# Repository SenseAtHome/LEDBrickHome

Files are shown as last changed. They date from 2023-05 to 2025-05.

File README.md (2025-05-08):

# LEDBrickHome

Wi-Fi controller compatible with various Lego Lighting kits, designed to enable integration of lighting into Home Assistant via ESPHome.  Supports single colour and RGB dimmable lights, lighting effects and use in scenes.

Video of lighting in action

## Versions

> [!WARNING]  
> Versions up to and included v1.1 have a hardware design issue that prevents the use of USB-C to USB-C cables.  They will work correctly with USB-A to USB-C cables.

Different versions of LEDBrickHome may exist in the future with different numbers of output connectors (e.g. to reduce cost or size).

To maximise available number of channels, RGB (4-pin) outputs are shared with single colour (2-pin) outputs.  In other words, a 16 PWM controller can support a total of 16 different outputs of a single colour, but for each RGB output used, three single colour outputs are lost.

| Version | Total PWM Outputs | 2-pin outputs | 4-pin outputs | Dimensions |
| --- | --- | --- | --- | --- |
| 16ch-v1.0 | 16 | 16 | 5 | 96 x 45 mm |
| 16ch-v1.1 | 16 | 16 | 5 | 68 x 45 mm |

### 16ch-v1

16ch-v1 is based on an ESP32-WROOM (exact memory size does not matter), uses a CP2102N ([drivers](https://www.silabs.com/developers/usb-to-uart-bridge-vcp-drivers?tab=downloads)) for it's USB->UART bridge, and is powered by a USB-C connector.  Outputs are grouped in blocks and identified on the silkscreen which 2-pin outputs are shared with 4-pin outputs.

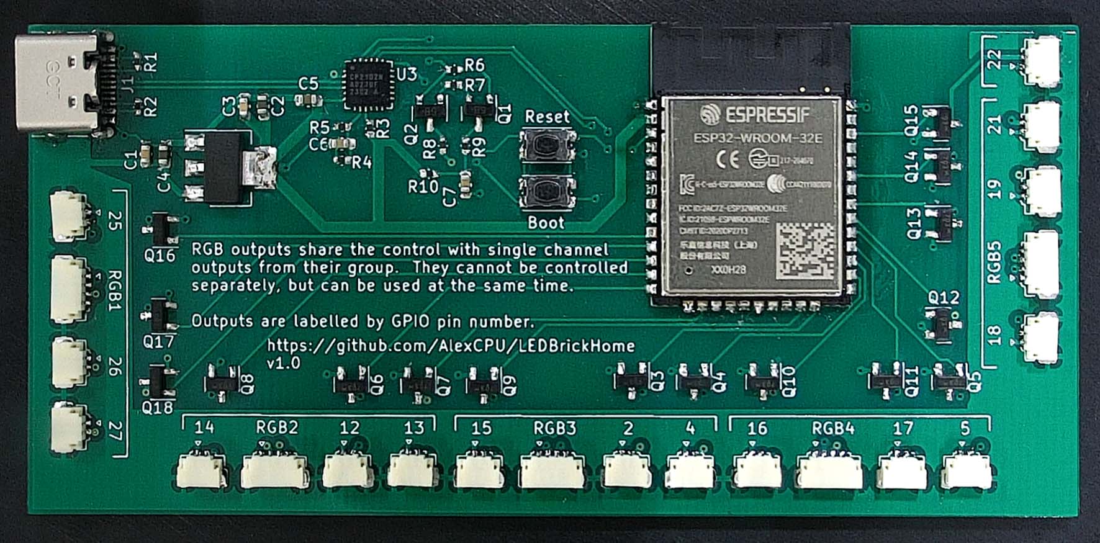
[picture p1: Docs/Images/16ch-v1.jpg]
PCB showing ESP32 and output connectors


### 16ch-v1.1

16ch-v1.1 is a smaller version of the previous 16ch design, using a CH340C ([drivers](http://www.wch-ic.com/downloads/CH341SER_ZIP.html)) for it's USB->UART bridge, but is otherwise functionally identical.

## Effects
Various effects are available in ESPHome, which are explained in the [documentation](https://esphome.io/components/light/index.html#light-effects), some of these are included in the code examples already.  For flickering torch effects, the default flicker intensity (of 1.5%) will want to be increased.  The demo video above has flicker set at 10%.

## Compatibility

LEDBrickHome is compatible with lighting kits that use a JST SUR connector with 5V on pin 1, and switched 0V on pin 2 (plus pins 3 & 4 for RGB connectors).

The below table shows the results of our testing.  You should verify connector type and pinout yourself for your own project.

| Light System | Compatible? | Notes |
| --- | --- | --- |
| Light My Bricks V1 | :white_check_mark: | | 
| Light My Bricks V2 | :x: | Swapped to a flat ribbon style connector |
| Briksmax V1 | :white_check_mark: | |
| Briksmax V2 | :x: | Similar but not compatible with JST SUR |
| Kyglaring | :white_check_mark: | |

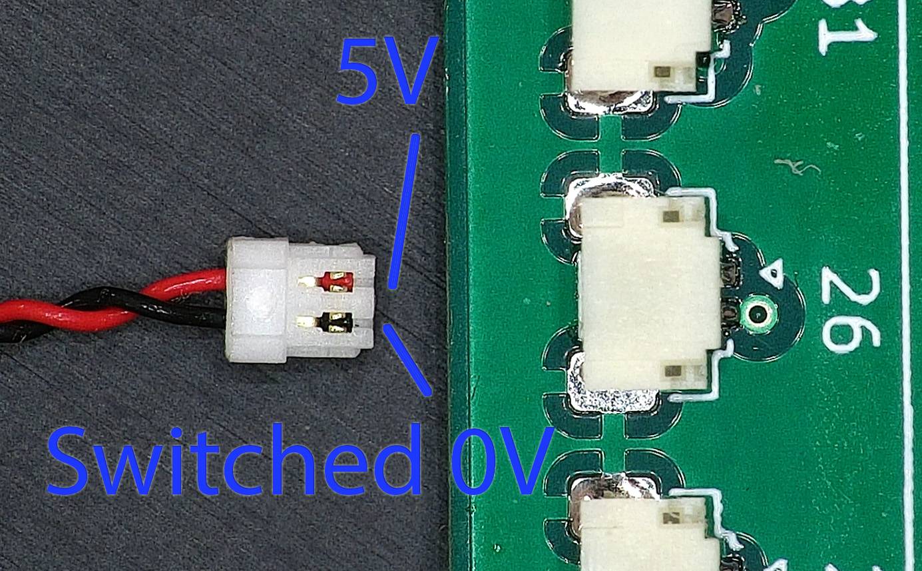
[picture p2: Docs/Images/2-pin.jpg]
2 pin JST SUR connector


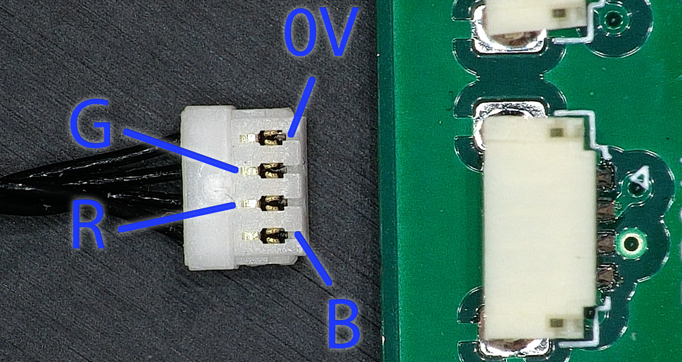
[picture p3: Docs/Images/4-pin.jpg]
4 pin JST SUR connector

Note, order of Red, Green and Blue channels is not important and can be changed in your configuration file.

## PCB Design

The PCB design is created in KiCAD V7, and is a simple 2-layer PCB.

## Tips
* Do not add the web server to the code, this seems to cause the ESP32 to reboot regularly.
* Boot and Reset buttons are included, but shouldn't be required for programming
* Original ESP32's are used rather than newer parts (e.g. S3, C3, etc.) as the original parts support 16 PWM outputs, whereas the newer parts only support 8 PWM outputs.
* RGB outputs may need their output channels swapping if the colour mapping is wrong. i.e. if you ask for Red but get Green, change the appropriate lines in your configuration file.

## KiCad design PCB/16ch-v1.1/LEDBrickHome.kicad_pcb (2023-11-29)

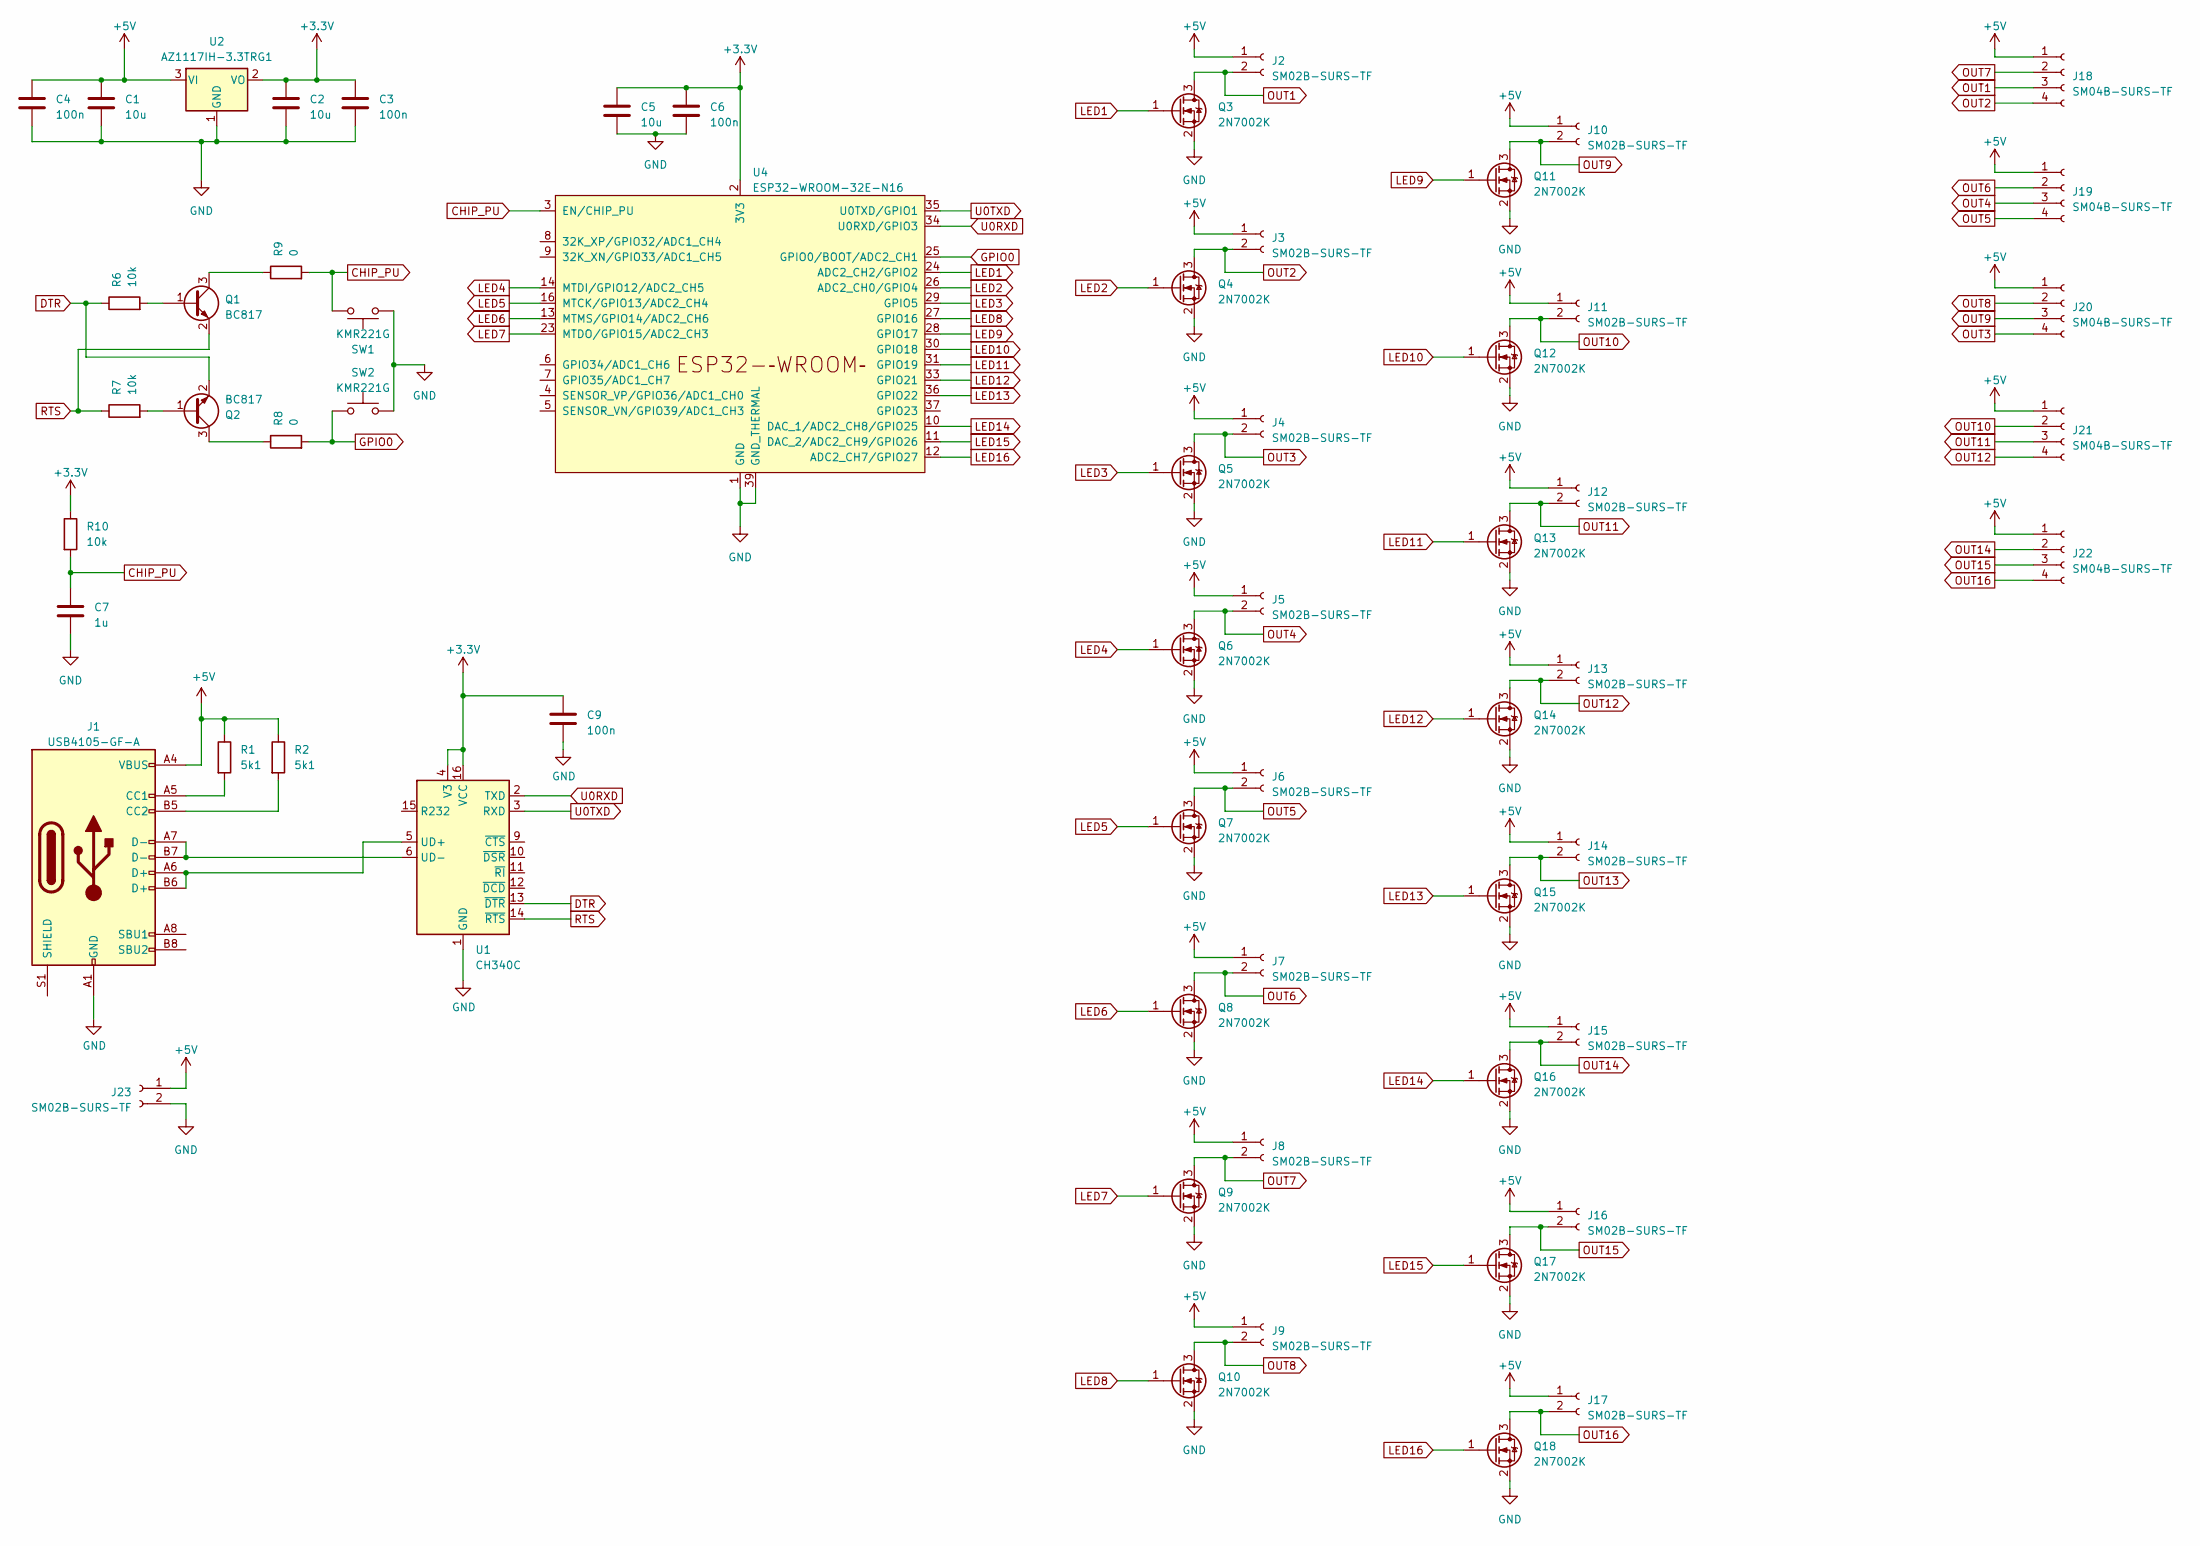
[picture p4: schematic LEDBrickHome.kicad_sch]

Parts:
C1, C2, C5: 10u; C_0603_1608Metric
C3, C4, C6, C9: 100n; C_0603_1608Metric
C7: 1u; C_0603_1608Metric
J1: USB4105-GF-A; USB_C_Receptacle_GCT_USB4105-xx-A_16P_TopMnt_Horizontal
J2, J3, J4, J5, J6, J7, J8, J9, J10, J11, J12, J13, J14, J15, J16, J17, J23: SM02B-SURS-TF; JST_SUR_SM02B-SURS-TF_1x02-1MP_P0.80mm_Horizontal
J18, J19, J20, J21, J22: SM04B-SURS-TF; JST_SUR_SM04B-SURS-TF_1x04-1MP_P0.80mm_Horizontal
Q1, Q2: BC817; SOT-23
Q3, Q4, Q5, Q6, Q7, Q8, Q9, Q10, Q11, Q12, Q13, Q14, Q15, Q16, Q17, Q18: 2N7002K; SOT-23
R1, R2: 5k1; R_0402_1005Metric
R6, R7, R10: 10k; R_0402_1005Metric
R8, R9: 0; R_0402_1005Metric
SW1, SW2: KMR221G; SW_Push_1P1T_NO_CK_KMR2
U1: CH340C; SOIC-16_3.9x9.9mm_P1.27mm
U2: AZ1117IH-3.3TRG1; SOT-223-3_TabPin2
U4: ESP32-WROOM-32E-N16; ESP32-WROOM-32E

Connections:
+3.3V: C2.2, C3.2, C5.2, C6.2, C9.2, R10.1, U1.4 (V3), U1.16 (VCC), U2.2 (VO), U4.2 (3V3)
+5V: C1.2, C4.2, J1.A4 (VBUS), J1.A9 (VBUS), J1.B4 (VBUS), J1.B9 (VBUS), J2.1, J2.MP, J3.1, J3.MP, J4.1, J4.MP, J5.1, J5.MP, J6.1, J6.MP, J7.1, J7.MP, J8.1, J8.MP, J9.1, J9.MP, J10.1, J10.MP, J11.1, J11.MP, J12.1, J12.MP, J13.1, J13.MP, J14.1, J14.MP, J15.1, J15.MP, J16.1, J16.MP, J17.1, J17.MP, J18.1, J18.MP, J19.1, J19.MP, J20.1, J20.MP, J21.1, J21.MP, J22.1, J22.MP, J23.1, J23.MP, R1.1, R2.1, U2.3 (VI)
CHIP_PU: C7.2, R9.2, R10.2, SW1.1, U4.3 (EN/CHIP_PU)
DTR: Q2.2 (E), R6.1, U1.13 (~DTR)
GND: C1.1, C2.1, C3.1, C4.1, C5.1, C6.1, C7.1, C9.1, J1.A1 (GND), J1.A12 (GND), J1.B1 (GND), J1.B12 (GND), J23.2, Q3.2 (S), Q4.2 (S), Q5.2 (S), Q6.2 (S), Q7.2 (S), Q8.2 (S), Q9.2 (S), Q10.2 (S), Q11.2 (S), Q12.2 (S), Q13.2 (S), Q14.2 (S), Q15.2 (S), Q16.2 (S), Q17.2 (S), Q18.2 (S), SW1.2, SW2.2, U1.1 (GND), U2.1 (GND), U4.1 (GND), U4.15 (GND), U4.38 (GND), U4.39 (GND_THERMAL)
GPIO0: R8.2, SW2.1, U4.25 (GPIO0/BOOT/ADC2_CH1)
LED1: Q3.1 (G), U4.24 (ADC2_CH2/GPIO2)
LED2: Q4.1 (G), U4.26 (ADC2_CH0/GPIO4)
LED3: Q5.1 (G), U4.29 (GPIO5)
LED4: Q6.1 (G), U4.14 (MTDI/GPIO12/ADC2_CH5)
LED5: Q7.1 (G), U4.16 (MTCK/GPIO13/ADC2_CH4)
LED6: Q8.1 (G), U4.13 (MTMS/GPIO14/ADC2_CH6)
LED7: Q9.1 (G), U4.23 (MTDO/GPIO15/ADC2_CH3)
LED8: Q10.1 (G), U4.27 (GPIO16)
LED9: Q11.1 (G), U4.28 (GPIO17)
LED10: Q12.1 (G), U4.30 (GPIO18)
LED11: Q13.1 (G), U4.31 (GPIO19)
LED12: Q14.1 (G), U4.33 (GPIO21)
LED13: Q15.1 (G), U4.36 (GPIO22)
LED14: Q16.1 (G), U4.10 (DAC_1/ADC2_CH8/GPIO25)
LED15: Q17.1 (G), U4.11 (DAC_2/ADC2_CH9/GPIO26)
LED16: Q18.1 (G), U4.12 (ADC2_CH7/GPIO27)
unnamed: J1.A5 (CC1), R1.2
unnamed: J1.B5 (CC2), R2.2
unnamed: Q1.1 (B), R6.2
unnamed: Q1.3 (C), R9.1
unnamed: Q2.1 (B), R7.2
unnamed: Q2.3 (C), R8.1
unnamed: J1.A6 (D+), J1.B6 (D+), U1.5 (UD+)
unnamed: J1.A7 (D-), J1.B7 (D-), U1.6 (UD-)
OUT1: J2.2, J18.3, Q3.3 (D)
OUT2: J3.2, J18.4, Q4.3 (D)
OUT3: J4.2, J20.4, Q5.3 (D)
OUT4: J5.2, J19.3, Q6.3 (D)
OUT5: J6.2, J19.4, Q7.3 (D)
OUT6: J7.2, J19.2, Q8.3 (D)
OUT7: J8.2, J18.2, Q9.3 (D)
OUT8: J9.2, J20.2, Q10.3 (D)
OUT9: J10.2, J20.3, Q11.3 (D)
OUT10: J11.2, J21.2, Q12.3 (D)
OUT11: J12.2, J21.3, Q13.3 (D)
OUT12: J13.2, J21.4, Q14.3 (D)
OUT13: J14.2, Q15.3 (D)
OUT14: J15.2, J22.2, Q16.3 (D)
OUT15: J16.2, J22.3, Q17.3 (D)
OUT16: J17.2, J22.4, Q18.3 (D)
RTS: Q1.2 (E), R7.1, U1.14 (~RTS)
U0RXD: U1.2 (TXD), U4.34 (U0RXD/GPIO3)
U0TXD: U1.3 (RXD), U4.35 (U0TXD/GPIO1)

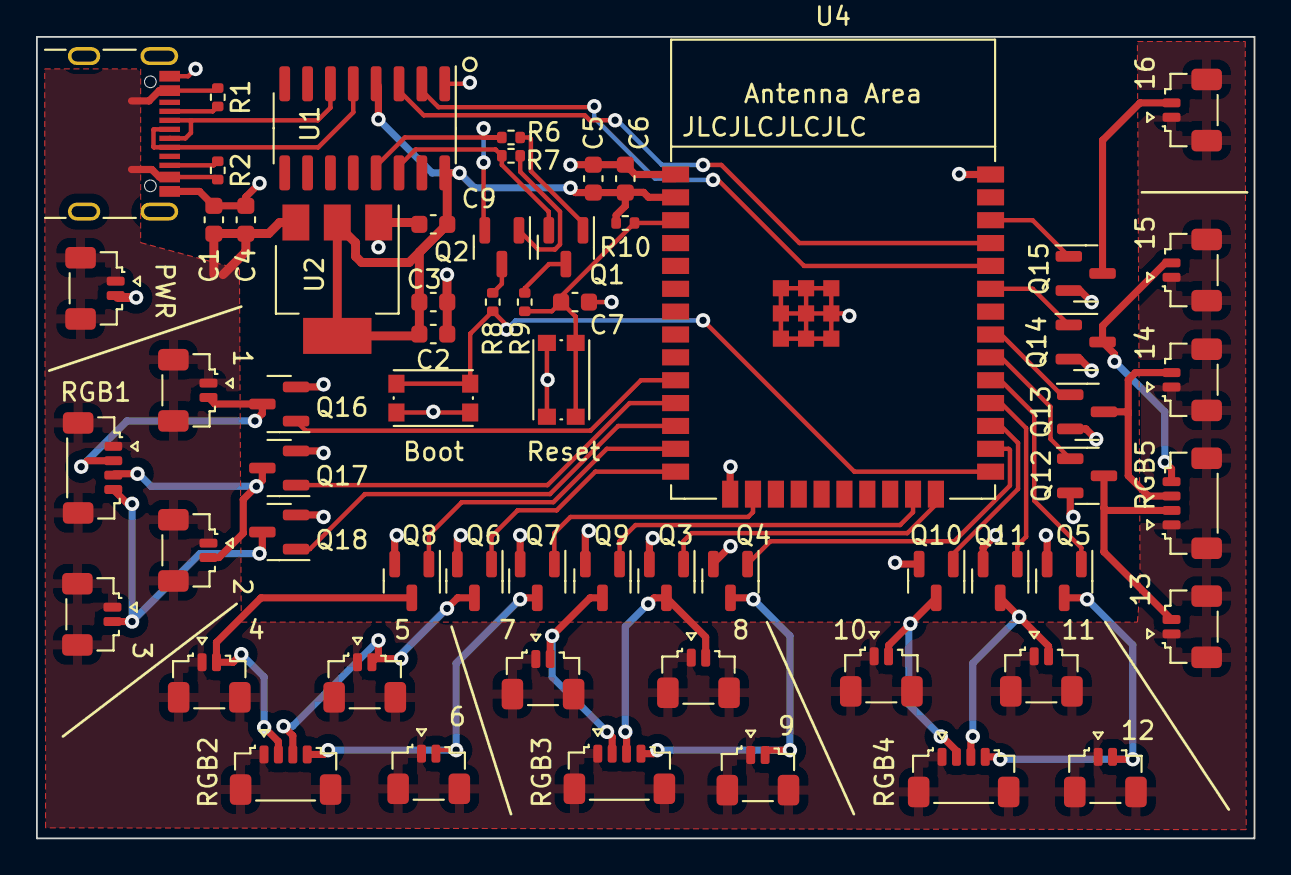
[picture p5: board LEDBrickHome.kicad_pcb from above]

Board: 2 copper layers, 67.6 x 44.5 mm, 61 parts (0 on the bottom side), 49 nets.

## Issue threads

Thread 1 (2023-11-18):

hello nice project!

platini76, 2023-11-18:
please can I know where can I find the board?
thanks!

AlexCPU, 2023-11-19:
There should be everything you need in this repo to build your own, or you can order them from here: https://xelaser.co.uk/product/ledbrickhome-16-channel-version/

Closed 2023-11-19.

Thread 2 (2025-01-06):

Question: Any plans on updates

kl4n4, 2025-01-06:
Hi,

First of all: thank you sharing this awesome project so openly! I was looking for exactly this (some option to control my LEGO lights with HomeAssistant). But since I unfortunately lack the electronic skills to design and build my own ESP32-based PCB I immediately ordered one of yours from xelaser. Unluckily I did not realize LightMyBricks/Briksmax have changed their connectors in the meantime and are not longer using these JST SUR connector types :(

Do you have any plans on updating your PCB with these "Briksmax 2.0" connectors (I have no idea what type of connector this is exactly) but the unfortunately even stopped selling the old connector cables :/

Thanks and greetings from Austria :)

AlexCPU, 2025-01-08:
Oh that's really annoying!  If I can identify the connector then it's possibly, but some quick googling hasn't managed to find out any details about it.  The new LightMyBricks flat ribbon cable might be more of a problem.

As for your existing kit, if you search AliExpress for "lego light cables", you'll get plenty of cheap options for the old connectors, so you could cut off the new ones, cut the AliExpress cables in half, and solder them together, to convert your kit back to the old connectors to work with the board you've got.

Nensec, 2025-01-09:
I've been working on adapting your idea but using generic esp32 devkit boards instead ontop of an adapter board for the connectors and power supply. So if you find out what connectors they use do share that information. I did ask lightmybricks myself already and I got a canned response back that they are proprietary, so one has to get creative on that one.

I have an LMB2.0 set at home here so I will be experimenting a bit on what makes for a secure connection. An obvious work around is using LMB2.0 converter bricks between the JST connectors and their proprietary ones, but that will get costly very quickly 😋

kl4n4, 2025-01-11:
Thanks for these inputs! I will be looking for alternative sources of the old cables and solder them to the new cables ;)

Closed 2025-01-11.

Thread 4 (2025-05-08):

Cannot get board connected with USB

bramstroker, 2025-05-08:
Hi @AlexCPU, thanks for your project — it was exactly what I needed for my MOC build.

I ordered the assembled board from xelaser and received it last week. I finally got around to installing it today, but I'm running into issues connecting the device via USB to flash the firmware.

I first tried on my MacBook Pro, and installed the CH340 driver. However, no new USB devices show up when I check with ls /dev/cu.*, and ESPHome Web also doesn't detect the device. I tried three different cables and all USB ports, and also held the BOOT button while connecting, but still no luck.

Next, I tried a Windows 10 PC, but I don’t hear any USB connection sound when plugging in the board. Even without drivers, I’d expect at least a connection tone.

At this point, I’m suspecting the board might be faulty, but I’m not entirely sure. Any advice on what else I could try?

AlexCPU, 2025-05-08:
Hi @bramstroker,

I did have some issues with USB cables on this latest batch that sound similar to what you are describing, I just found another cable which worked and assumed I had a dodgy cable.  However...

Having now investigated further, it looks like you've found a bug in the hardware design that you're probably more disposed to by only having USB-C ports on the MacBook Pro.

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

R1 and R2 should be pull-down resistors rather than pull-up resistors.  In their current configuration, they are set up to tell the USB-C interface that they are the "host" device, which is why your computer can't see anything, as both ends of the link are claiming to be the host.

I've confirmed this with some USB-C cables, laptops and charger/power-supplies.

If you use a USB-A to USB-C cable, it should power up fine.  And also work with an A-C adapter on the end of that cable (the A end has to be in the laptop not the PCB, as it defines the host end of the cable itself).

One final point, you shouldn't need to program it, they were all programmed and tested before shipping.  Once powered up with an A-C cable, it should put up a Wi-Fi access point for you to connect to and give your network details to.

bramstroker, 2025-05-09:
Thanks for your answer and clarification.

I completely missed the firmware was pre-installed. Just connected the board using a USB charger with A-C cable, and was able to connect to the provided ap. Set up my own WiFi and up and running.
Now I can take control in HA and upload modified firmware using OTA.

Thanks a lot!

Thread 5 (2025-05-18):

Request for PCB Modification Assistance

bramstroker, 2025-05-18:
First of all, thank you for sharing your fantastic PCB project. I’ve been using it as part of a large LEGO MOC I’ve been working on for nearly two years—a detailed church tower made of over 30,000 pieces. Your board has been instrumental in lighting up all the floors with RGB and white lights, and everything works superbly. I really appreciate your work and generosity in making this available.

The model will soon be displayed inside the actual church and later in a local museum. Since not all of these locations have WiFi, I’d like to add some physical push buttons to control the lights offline.

I managed to modify the ESPHome firmware and solder two wires directly to the ESP chip, but it feels quite fragile and not suitable for long-term use. Ideally, I’d love to have a modified version of the PCB that exposes a few additional GPIO pins through JST SUR connectors for button input.

For my needs, just 3 GPIOs and ground would be sufficient—so either one 4-pin connector (GND + 3 GPIO) or three separate plugs would work.
The GPIO pins need to support pullups, not every pin does.

Would you be open to helping with this modification? I’d be happy to pay for your time and effort. Please let me know if this is something you’d consider.

Thanks again for the amazing project

P.S. I couldn't find you contact information. If you'd like to discuss this further as Github issue tracker might not be the right place you can contact me on bgerritsen_at_gmail_dot_com

AlexCPU, 2025-06-04:
I'm very torn on the correct solution for this, mostly around the choice of connector.  I can see the options as:

**2-pin JST SUR**
- Doesn't add another line to the BOM.
- Could be used for extra LEDs (without hardware PWM), although lower voltage and drive current might be an issue.
- Board needs to be larger.

**4-pin JST SUR**
- Doesn't add another line to the BOM
- Could be used for extra RGB LEDs (without hardware PWM), although lower voltage and drive current might be an issue.
- Effectively custom to this request.
- Board needs to be larger.

**Pin Header**
- Could be left to the end user to add, therefore not adding a line to the BOM, keeping just one "active" version of the project.
- User needs to be able to solder to use.
- Board needs to be larger.

**Test points** (holes to solder your own wires to)
- User needs to be able to solder to use.
- Probably could be fitted on the existing board

So I think my preference would be test points, and they could be rolled up into the 1.2 update that fixes #4.

Finally (and I haven't checked this) you've said that GPIO34-39 don't have inbuilt pull-ups, in that case, there's only two pins left (GPIO32-33), so I'm curious which pins you are using.  In theory the UART and Boot pins can be reused, and if I was in control of the hardware, I would reuse them, but I don't think they're a great choice for public facing GPIOs as users could connect things that break the boot sequence, or programming functionality.

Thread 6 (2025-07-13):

Briksmaks V1.1

Schattenruf, 2025-07-13:
Hi,

I bought your Board and the briksmaks v1.1 Kit for barad dur. But this connector does not seem to be compatible as far as I can see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

The Board seems to have smaller connectors than the briksmaks ones. I think the recommandation about briksmaks need to be changed :(
Sadly that is what I went after...

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

AlexCPU, 2025-07-13:
Duplicate of #2

The readme/description was updated back in January to reflect the change of connector from various vendors including Briksmax, and has always had a note saying you should verify connectors and pinouts for your project. (https://github.com/SenseAtHome/LEDBrickHome/blame/1099f178986a1b3c88ba9959eac5e6fbd6b0459e/README.md#L38)

Your pictures show the new version two connector.  I expect the V1.1.0 on your box refers to the version of the Barad Dur kit.

Briksmax do have an adapter available that you can use to convert between the two connector types: https://www.briksmax.com/products/connector-converter-three-pack-resolving-compatibility-issues-between-new-and-old-connectors

Closed 2025-07-13.

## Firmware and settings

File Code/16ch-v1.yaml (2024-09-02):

substitutions:
  name: "ledbrickhome-16ch"
  friendly_name: "LEDBrickHome"
  project_name: "SenseAtHome.ledbrickhome-16ch"
  project_version: "1.0"
  hidden_ssid: "false"

esphome:
  name: "${name}"
  name_add_mac_suffix: true
  project:
    name: "${project_name}"
    version: "${project_version}"

esp32:
  board: esp32dev
  framework:
    type: arduino
    version: recommended

logger:

api:

ota:
  - platform: esphome

wifi:
  fast_connect: ${hidden_ssid}
  ap: {}

captive_portal:

improv_serial:

esp32_improv:
  authorizer: none
  
dashboard_import:
  package_import_url: github://AlexCPU/LEDBrickHome/Code/16ch-v1.yaml@main
  import_full_config: true

binary_sensor:
  - platform: status
    name: "${friendly_name} Status"

sensor:
  - platform: uptime
    name: "${friendly_name} Uptime"
    disabled_by_default: true

button:
  - platform: restart
    id: restart_button
    name: "${friendly_name} Restart"
  - platform: factory_reset
    name: Restart with Factory Default Settings

time:
  - platform: sntp

switch:
  - platform: factory_reset
    name: Factory Reset

text_sensor:
  - platform: wifi_info
    ip_address:
      name: "${friendly_name} IP Address"
      disabled_by_default: true

light:
# Details for each of the outputs.
# see https://esphome.io/components/light/index.html#light-effects for configuration
# of light effects

# Group 1:
# to use RGB light, uncomment it's section and comment the monochromatic lights
  - platform: monochromatic
    name: "Channel 1"
    output: output_ch1
    effects:
      - pulse:
      - flicker:
          intensity: 10%
      - strobe:
  - platform: monochromatic
    name: "Channel 2"
    output: output_ch2
    effects:
      - pulse:
      - flicker:
          intensity: 10%
      - strobe:
  - platform: monochromatic
    name: "Channel 3"
    output: output_ch3
    effects:
      - pulse:
      - flicker:
          intensity: 10%
      - strobe:
#  - platform: rgb
#    name: "RGB1"
#    # Output channels may need swapping to match the wiring of your light
#    red: output_ch1
#    green: output_ch2
#    blue: output_ch3
#    effects:
#      - pulse:
#      - flicker:
#      - strobe:
#      - random:

# Group 2:
# to use RGB light, uncomment it's section and comment the monochromatic lights
  - platform: monochromatic
    name: "Channel 4"
    output: output_ch4
    effects:
      - pulse:
      - flicker:
          intensity: 10%
      - strobe:
  - platform: monochromatic
    name: "Channel 5"
    output: output_ch5
    effects:
      - pulse:
      - flicker:
          intensity: 10%
      - strobe:
  - platform: monochromatic
    name: "Channel 6"
    output: output_ch6
    effects:
      - pulse:
      - flicker:
          intensity: 10%
      - strobe:
#  - platform: rgb
#    name: "RGB2"
#    # Output channels may need swapping to match the wiring of your light
#    red: output_ch4
#    green: output_ch5
#    blue: output_ch6
#    effects:
#      - pulse:
#      - flicker:
#      - strobe:
#      - random:

# Group 3:
# to use RGB light, uncomment it's section and comment the monochromatic lights
  - platform: monochromatic
    name: "Channel 7"
    output: output_ch7
    effects:
      - pulse:
      - flicker:
          intensity: 10%
      - strobe:
  - platform: monochromatic
    name: "Channel 8"
    output: output_ch8
    effects:
      - pulse:
      - flicker:
          intensity: 10%
      - strobe:
  - platform: monochromatic
    name: "Channel 9"
    output: output_ch9
    effects:
      - pulse:
      - flicker:
          intensity: 10%
      - strobe:
#  - platform: rgb
#    name: "RGB3"
#    # Output channels may need swapping to match the wiring of your light
#    red: output_ch7
#    green: output_ch8
#    blue: output_ch9
#    effects:
#      - pulse:
#      - flicker:
#      - strobe:
#      - random:

# Group 4:
# to use RGB light, uncomment it's section and comment the monochromatic lights
  - platform: monochromatic
    name: "Channel 10"
    output: output_ch10
    effects:
      - pulse:
      - flicker:
          intensity: 10%
      - strobe:
  - platform: monochromatic
    name: "Channel 11"
    output: output_ch11
    effects:
      - pulse:
      - flicker:
          intensity: 10%
      - strobe:
  - platform: monochromatic
    name: "Channel 12"
    output: output_ch12
    effects:
      - pulse:
      - flicker:
          intensity: 10%
      - strobe:
#  - platform: rgb
#    name: "RGB4"
#    # Output channels may need swapping to match the wiring of your light
#    red: output_ch10
#    green: output_ch11
#    blue: output_ch12
#    effects:
#      - pulse:
#      - flicker:
#      - strobe:
#      - random:

# Group 5:
# to use RGB light, uncomment it's section and comment the monochromatic lights
  - platform: monochromatic
    name: "Channel 13"
    output: output_ch13
    effects:
      - pulse:
      - flicker:
          intensity: 10%
      - strobe:
  - platform: monochromatic
    name: "Channel 14"
    output: output_ch14
    effects:
      - pulse:
      - flicker:
          intensity: 10%
      - strobe:
  - platform: monochromatic
    name: "Channel 15"
    output: output_ch15
    effects:
      - pulse:
      - flicker:
          intensity: 10%
      - strobe:
#  - platform: rgb
#    name: "RGB5"
#    # Output channels may need swapping to match the wiring of your light
#    red: output_ch13
#    green: output_ch14
#    blue: output_ch15
#    effects:
#      - pulse:
#      - flicker:
#      - strobe:
#      - random:

# Ungrouped light (always available)
  - platform: monochromatic
    name: "Channel 16"
    output: output_ch16
    effects:
      - pulse:
      - flicker:
          intensity: 10%
      - strobe:

# The output definitions should not need to be changed
output:
  - platform: ledc
    pin: GPIO25
    id: output_ch1
  - platform: ledc
    pin: GPIO26
    id: output_ch2
  - platform: ledc
    pin: GPIO27
    id: output_ch3
  - platform: ledc
    pin: GPIO14
    id: output_ch4
  - platform: ledc
    pin: GPIO12
    id: output_ch5
  - platform: ledc
    pin: GPIO13
    id: output_ch6
  - platform: ledc
    pin: GPIO15
    id: output_ch7
  - platform: ledc
    pin: GPIO2
    id: output_ch8
  - platform: ledc
    pin: GPIO4
    id: output_ch9
  - platform: ledc
    pin: GPIO16
    id: output_ch10
  - platform: ledc
    pin: GPIO17
    id: output_ch11
  - platform: ledc
    pin: GPIO5
    id: output_ch12
  - platform: ledc
    pin: GPIO18
    id: output_ch13
  - platform: ledc
    pin: GPIO19
    id: output_ch14
  - platform: ledc
    pin: GPIO21
    id: output_ch15
  - platform: ledc
    pin: GPIO22
    id: output_ch16

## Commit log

2023-05-29 Add 16ch-v1 prototype
    [LEDBrickHome.kicad_pcb, LEDBrickHome.kicad_sch]
2023-05-29 prototype 16ch yaml code
2023-06-07 Add 16ch-v1.1
    [LEDBrickHome.kicad_pcb, LEDBrickHome.kicad_sch]
2023-06-25 Add missing Silkscreen + fix spelling mistake
    [LEDBrickHome.kicad_pcb]
2023-11-22 Add factory reset button
2023-11-29 Update URL
    [LEDBrickHome.kicad_pcb]
2025-05-08 Add warning about USB-C cables
